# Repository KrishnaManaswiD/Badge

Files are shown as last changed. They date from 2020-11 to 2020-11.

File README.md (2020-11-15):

# Badge
A congratulatory gift for my firends who completed their PhDs with me.   
Front: an engraved name badge with a built in micro-controller and a ruler to measure their tiny egos with.  
Back: a pictorial representation of our theses and a battery holder with a magnetic piece.  

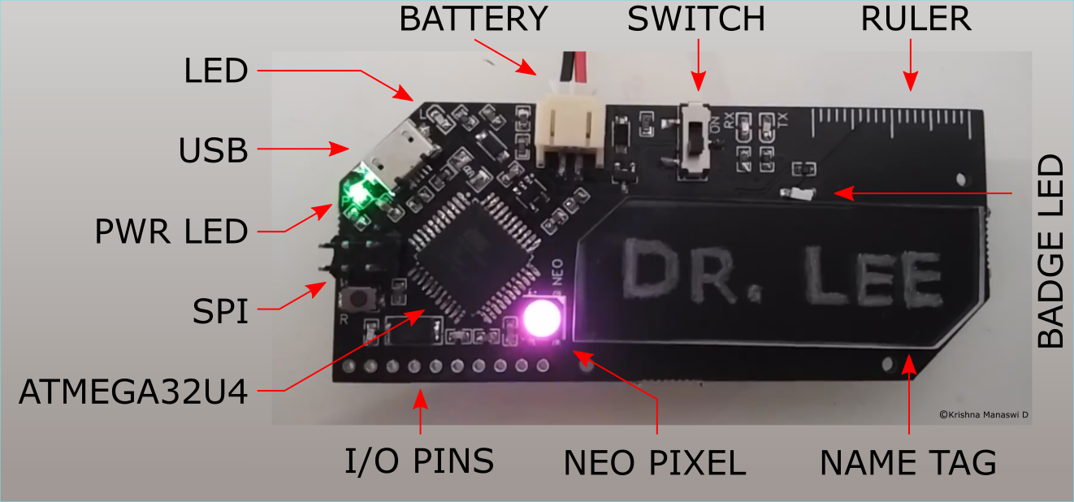
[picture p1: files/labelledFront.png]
The front


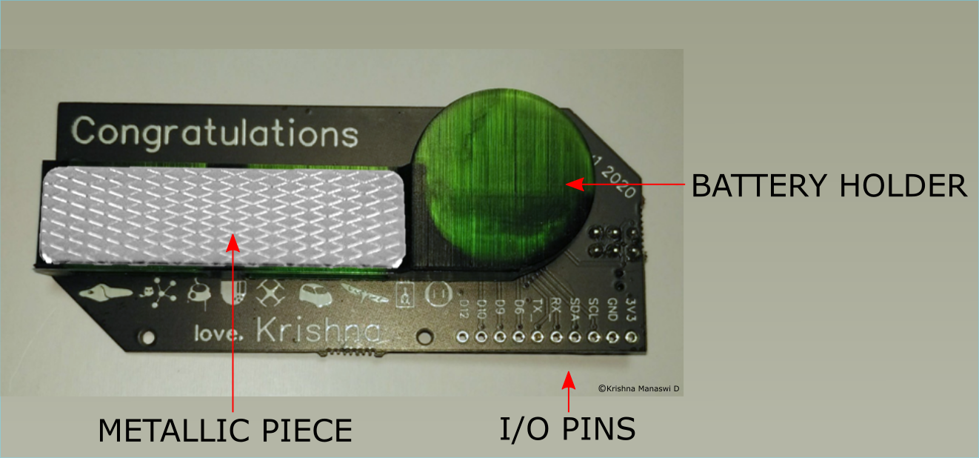
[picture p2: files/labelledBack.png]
The back


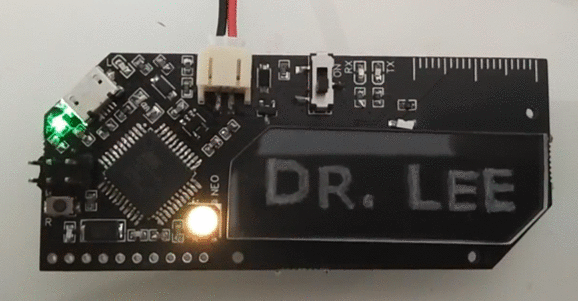
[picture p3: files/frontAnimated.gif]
The badge


- Instructions on building and programming the badge are [here](https://github.com/KrishnaManaswiD/Badge/blob/main/files/Instructions.md).  

- The gerber files can be downloaded from [here](https://github.com/KrishnaManaswiD/Badge/blob/main/files/Gerber_PCB_2020-01-05%2022_20_36.zip).  

- An interactive BOM is located [here](https://htmlpreview.github.io/?https://github.com/KrishnaManaswiD/Badge/blob/main/files/ibom.html). You can also download a csv version from [here](https://github.com/KrishnaManaswiD/Badge/blob/main/files/BOM.csv). 

- A schematic of the circuit is [here](https://github.com/KrishnaManaswiD/Badge/blob/main/files/Schematic_2020-08-21.pdf).  

I used [JLCPCB](https://jlcpcb.com/) to get the boards manufactured. This was the first time that I tried panelising the boards and I am pleased with the resutls.
The black silk screen looks nice. Pictures on the board were printed in sufficient detail. The board was designed using [EasyEDA](https://easyeda.com/). I sourced all the components except the magnetic badge pieces from [LCSC](https://lcsc.com/).

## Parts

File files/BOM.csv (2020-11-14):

Quantity | Name | Designator | Footprint | Manufacturer Part | Manufacturer | Supplier | Supplier Part
2 | 180pF | C1,C2 | 603 | 0603B181K500NT | FH | LCSC | C1598
6 | 10uF | C3,C4,C5,C6,C7,C8 | 603 | CL10A106MP8NNNC | SAMSUNG | LCSC | C85713
1 | 100nF | C9 | C0603 | CL10B104JB8NNNC | SAMSUNG | LCSC | C24452
1 | 1uF | C10 | C0603 | 0603F105M160NT | FH | LCSC | C1689
2 | SCHOTTKY | D1,D2 | SOD-123_L2.8-W1.8-LS3.7-RD | SS0520-R1-00001 | PANJIT International | LCSC | C398783
1 | nSMD025-30V | F1 | 1206 | nSMD025-30V | TECHFUSE | LCSC | C70070
1 | JST_2MM_MALE | J1 | JST-2-SMD | S2B-PH-SM4-TB(LF)(SN) | JST | LCSC | C295747
1 | RED | LED4 | LED0603-R-RD | 19-217/R6C-AL1M2VY/3T | EVERLIGHT | LCSC | C72044
1 | WS2812B | NEO | LED-SMD_4P-L5.0-W5.0-BL | WS2812B | Worldsemi | LCSC | C114585
1 | GREEN | PWR | LED0603-R-RD | 19-217/GHC-YR1S2/3T | EVERLIGHT | LCSC | C72043
1 | DMG3415U-7 | Q1 | SOT-23-3_L2.9-W1.6-P1.90-LS2.8-BR-CW | DMG3415U-7 | Diodes Incorporated | LCSC | C96616
2 | 22 | R1,R2 | 603 | RS-03K220JT | FH | LCSC | C96423
2 | 10K | R3,R8 | 603 | 0603WAF1002T5E | UniOhm | LCSC | C25804
1 | 150K | R4 | 603 | 0603WAF1503T5E | UniOhm | LCSC | C22807
4 | 1K | R5,R6,R7,R9 | 603 | 0603WAJ0102T5E | UniOhm | LCSC | C25585
1 | 100 | R10 | R0603 | 0603WAJ0101T5E | UniOhm | LCSC | C25201
1 | TSA343G00D-250J2 | SW1 | SW-SMD_L4.0-W2.9-P4.15-EH | TSA343G00D-250J2 | BRIGHT | LCSC | C354947
1 | SS-3235D-03-L2 | SW2 | SW-SMD_SS-3235D-03-L2.00 | SS-3235D-03-L2 | XKB Enterprise | LCSC | C381097
2 | BLUE | TX,RX | LED0603-R-RD | 19-217/BHC-ZL1M2RY/3T | EVERLIGHT | LCSC | C72041
1 | ATMEGA32U4-AU | U1 | QFP-44_L10.0-W10.0-P0.80-LS13.2-BL | ATMEGA32U4-AU | MICROCHIP | LCSC | C44854
1 | LP2981-33DBVR | U2 | SOT-23-5_L3.0-W1.7-P0.95-LS2.8-BL | LP2981-33DBVR | TI | LCSC | C129997
1 | SPI Header 6Pin | U3 | SPI HEADER
1 | micro 5P_C77238 | USB1 | MICRO-USB_MICRO-USB-17 | - | LCSC | LCSC | C77238
1 | 8MHZ | X1 | OSC-SMD_L5.0-W3.2 | G5308000201080 | JGHC | LCSC | C390781
10 | hole | 3V3_TAP,GND_TAP,TX_TAP,RX_TAP,SDA_TAP,SCL_TAP,D6/A7/PWM,D9/A9/PWM,D10/A10/PWM,D12/A11 | HOLE | GK001
1 | JST_2MM_Female |  |  | PHR-2 | JST | LCSC | C157955
2 | JST_FEMALE_Crimp |  |  | SPH-002T-P0.5S | JST | LCSC | C111515
1 | LED for Display |  |  | 99-213UMC/2437860/TR8 | Everlight Elec | LCSC | C329181
1 | Magnet Piece |  |  |  |  | Amazon

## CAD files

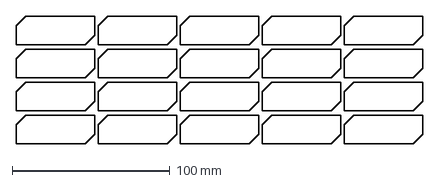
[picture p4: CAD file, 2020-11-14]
files/nameTag.dxf
258.0 x 81.0 mm

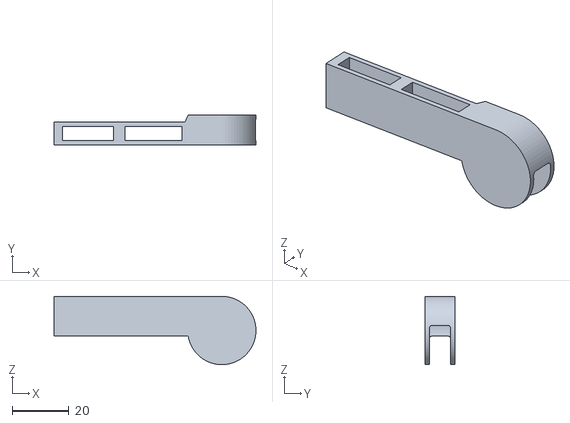
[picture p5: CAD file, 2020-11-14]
files/batteryHolder.stl
71.0 x 10.5 x 24.0

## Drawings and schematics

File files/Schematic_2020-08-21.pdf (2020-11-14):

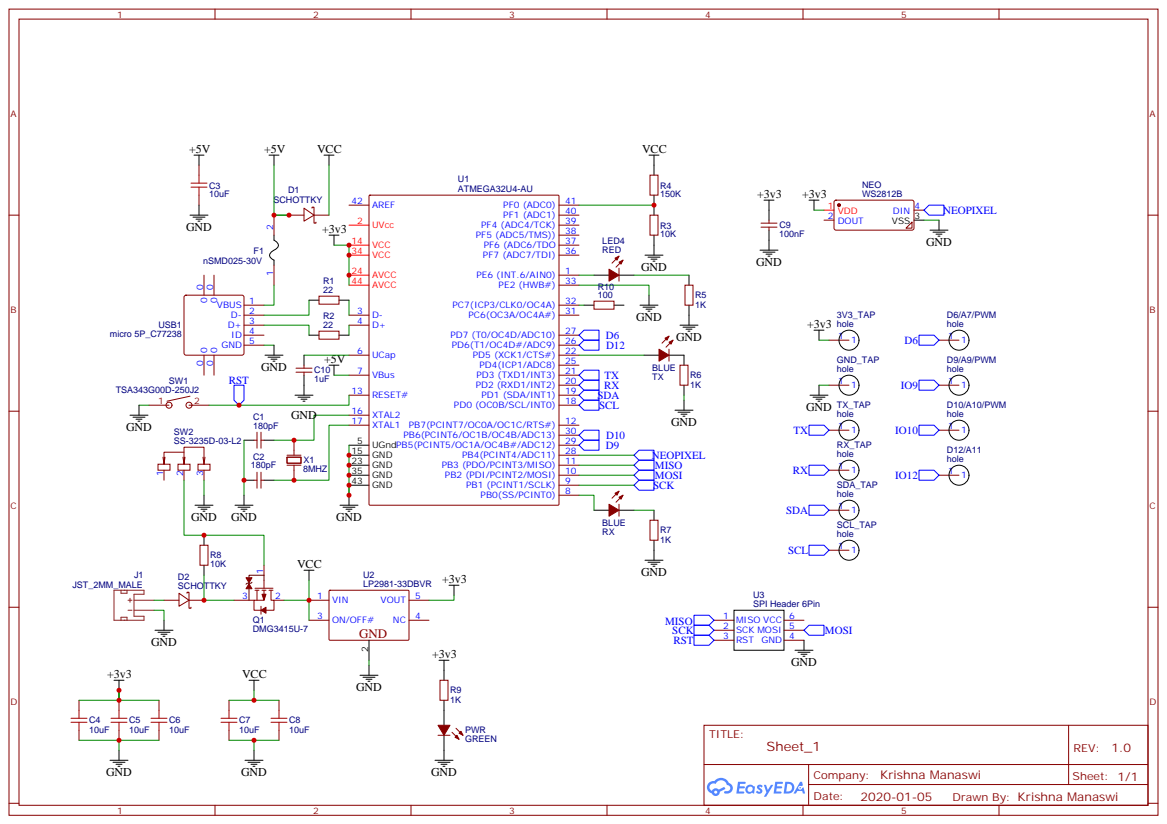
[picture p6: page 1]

PB7(PCINT7/OC0A/OC1C/RTS#) 12
PB2 (PDI/PCINT2/MOSI) 10 PB3 (PDO/PCINT3/MISO) 11 PB4(PCINT4/ADC11) 28 PB5(PCINT5/OC1A/OC4B#/ADC12) 29 PB6(PCINT6/OC1B/OC4B/ADC13) 30

Drawn By: Krishna Manaswi

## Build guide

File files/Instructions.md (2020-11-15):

# Instructions

## Assembly
1. Solder all the components.
2. The name tag is laser-cut out of acrylic. Download the file [here](https://github.com/KrishnaManaswiD/Badge/blob/main/files/nameTag.dxf). I engraved the name by hand, using a rotary tool with a ball attachment. I then glued it to the front of the badge.
3. The battery holder is 3D printed and affixed to the back of the badge. The STL file is located [here](https://github.com/KrishnaManaswiD/Badge/blob/main/files/batteryHolder.stl). I printed it on an Anycubic Photon S.  
4. The metallic piece of the [magnetetic clip](https://www.amazon.com/Magnetic-Name-Badge-Holder/s?k=Magnetic+Name+Badge+Holder) is finally glued to the battery holder.

## Powering the badge
The battery holder is designed to hold two CR2032 batteries (3V each) in the circular portion or a small 3.7V LiPo battery in the rectangular section below the metallic piece.
The badge has an onboard regulator that supplies 3.3V to the chips. Connect the batteries using the JST header. **Be sure to check the polarity.**

The back

## Programming
The board is very similar in design to the [Adafruit Flora](https://www.adafruit.com/product/659). There are a few differences like extra I/O pins and LEDs but you can treat it in a similar manner. To set it up like an Adafruit Flora, you need to burn the correct bootloader. The advantage is that the Arduino IDE recognises the board as a Flora and you can program it through the USB port. The disadvantage is that the additional pin functionality is lost.  

Alternatively, you can treat the board like a programmable chip and write custom code on it through the SPI header.  

Follow the steps below to set it up in whichever way you want. Both methods require the use of a programmer. An Arduino UNO that is set up as an ISP will do fine.

### Convert an Arduino UNO to a programmer
1. Connect a working Arduino UNO to your computer.  
2. Using the Arduino IDE, burn the ArduinoISP sketch from the provided examples.  

Your Arduino UNO is now a programmer. For more details, you can refer [here](https://www.arduino.cc/en/Tutorial/BuiltInExamples/ArduinoISP)

### Connecting the Arduino UNO to the badge
You will need to connect the SPI headers as shown below.
| UNO |  Badge  |
|---|:---:|
| Pin 10  |  RESET  |
| Pin 11  |  MOSI |
| Pin 12  |  MISO |
| Pin 13  |  SCK |
| GND |  GND |
| 3V3 |  3V3 |

If you are looking at the front of the badge, the SPI header is to the left of the ATMEGA32U4 chip. The pins are as follows. The square pad is the GND pin in my design.   
|  RESET  | SCK |  MISO  |
|---|:---:|---:|
| **GND** |**MOSI** |**VCC** |

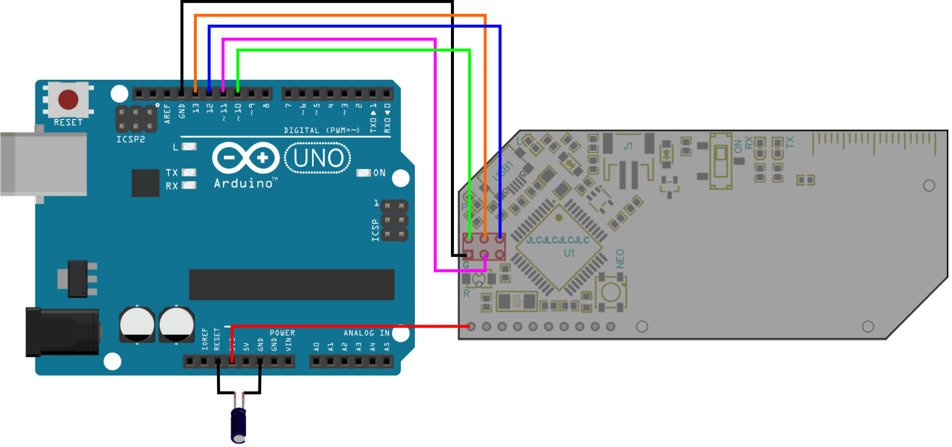
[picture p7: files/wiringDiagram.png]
The front


Note: You will also need to use a 10µF electrolytic capacitor between RESET and GND on the UNO when using it as a programmer. Connect this only after burning the ArduinoISP sketch.  

Additional note: The VCC pin on the badge pcb is not connected to anything else. To power the board during programming, connect the 3V3 pin on the UNO to the 3v3 pin on the badge (first hole on the bottom left). **Be careful that you are using the 3V3 pin from the UNO and not the 5V pin. The badge only runs at 3.3V. You should also be careful that the connection is stable for the entire duration of the programming and does not dislodge as the badge is being programmed.** Else, you risk bricking the board. You can also try providing power with a battery.  

### Option 1: Burning the Adafruit Flora bootloader to the badge
1. First, make sure you have the relevant bootloader. Install the Adafruit boards to the Arduino IDE by following the isntructions [here](https://learn.adafruit.com/adafruit-arduino-ide-setup/arduino-1-dot-6-x-ide).
2. Connect the UNO to the badge as described in the section above. Double check the 3V3 cable.
3. Under Tools -> Board, choose Adafruit Flora.
4. Under Tools -> Port, choose the port that the UNO is connected to.
5. Under Tools -> Programmer, choose Arduinoo as ISP
6. When you are ready, click on Burn Bootloader in the Tools menu.  

Your board should now be detected as an Adafruit Flora. You might have to install the relevant drivers on Windows. See [here](https://learn.adafruit.com/getting-started-with-flora/windows-setup). You dont need the UNO anymore. Use the badge as if you use a regular Arduino. A ton of Flora related tutorials can be found [here](https://learn.adafruit.com/getting-started-with-flora/flora-projects).

### Option 2: No bootloader. Use an UNO to upload a sketch to the badge each time
1. In the Arduino IDE, open the sketch that you want to write to the badge. A demo code is [here](https://github.com/KrishnaManaswiD/Badge/blob/main/files/demo.ino).
2. Coonect the UNO to the badge as described in the section above. Double check the 3V3 cable. 
3. Under Tools -> Port, choose the port that the UNO is connected to.
4. Under Tools -> Programmer, choose Arduinoo as ISP 
5. When ready, go to Sketch -> Upload using programmer. This will write the sketch to the badge.  

If you disconnect the UNO, connect a battery and turn the badge ON, you should see the sketch running.  
You need to use the UNO, that has been set up as a programmer, each time you want to upload a new sketch.  

## Note to friends who received the badges as a gift
I programmed the board using the second method. It is running the demo code that I linked above.  
The red LED at the top left of the board flashes once as soon as you turn on the badge.  
This is followed by two cycles of the Neopixel running through the colours of the rainbow.  
Finally, the LED on the badge glows to highlight the name.  

The badge

## Addressable LEDs and I/O
1. The red LED in the top left of the badge is on pin 7.
2. The LED above the name tag is on pin 13.
3. The neopixel is on pin 8.
4. I/O pins at the bottom are pins 6, 9, 10 and 12.

## Mistakes in the design
1. On the top silkscreen, the ON side of the power switch is indicated incorrectly. The switch is ON when it is towards the bottom end of the badge and OFF when it is towards the top end.
2. The USB connector needs to be grounded. The pcb does not do it. A simple fix is to solder a 0V resistor between the USB casing and a nearby GND pin.
3. The VCC pin on the SPI header is not connected to anything else. This means that during programming, power must be suplied to the board through the 3v3 pin.

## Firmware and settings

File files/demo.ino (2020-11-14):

/* Demo code to run on the badge
 *  Author: Krishna Manaswi Digumarti
 *  Date: Sep 2020
 *  Based on Adafruit's neopixel code
 */

#include <Adafruit_NeoPixel.h>

#define PIN 8
Adafruit_NeoPixel strip = Adafruit_NeoPixel(1, PIN, NEO_GRB + NEO_KHZ800);

int redlED = 7;
int badgeLED = 13;
bool start = false;

void setup()
{
  strip.begin();
  strip.setBrightness(50);
  strip.show(); // Initialize all pixels to 'off'

  pinMode(redlED, OUTPUT); 
  pinMode(badgeLED, OUTPUT);
}

void loop()
{

  if (start == false)
  {
    digitalWrite(redlED, HIGH);   // turn the LED ON
    delay(500);                   // wait for half a second
    digitalWrite(redlED, LOW);    // turn the LED OFF
    delay(500); 
  
    rainbowCycle(20);
    start = true;
  }
  else
  {
    strip.clear();
    strip.show();
    delay(100);
    digitalWrite(badgeLED, HIGH);
  }
}

void rainbowCycle(uint8_t wait)
{
  uint16_t i, j;

  for(j=0; j<256*2; j++) // 2 cycles of all colors on wheel
  { 
    for(i=0; i< strip.numPixels(); i++) 
    {
      strip.setPixelColor(i, Wheel(((i * 256 / strip.numPixels()) + j) & 255));
    }
    strip.show();
    delay(wait);
  }
}

// Input a value 0 to 255 to get a color value.
// The colours are a transition r - g - b - back to r.
uint32_t Wheel(byte WheelPos)
{
  WheelPos = 255 - WheelPos;
  if(WheelPos < 85)
  {
   return strip.Color(255 - WheelPos * 3, 0, WheelPos * 3);
  }
  else if(WheelPos < 170)
  {
    WheelPos -= 85;
   return strip.Color(0, WheelPos * 3, 255 - WheelPos * 3);
  }
  else 
  {
   WheelPos -= 170;
   return strip.Color(WheelPos * 3, 255 - WheelPos * 3, 0);
  }
}

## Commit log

2020-11-13 added interactive bom
2020-11-14 added csv bom and some images
    [BOM.csv]
2020-11-14 added a powerpoint slide to make gif images
2020-11-14 Added gerbers and schematic
2020-11-14 added links to jlcpcb, bom and schematic
2020-11-14 edited bom
2020-11-14 removed pcb.json
2020-11-14 add battery holder stl. simplified file structure
    [BOM.csv, batteryHolder.stl]
2020-11-14 added assembly instructions
2020-11-14 added name tag dxf file
    [nameTag.dxf]
2020-11-15 added wiring diagram
2020-11-15 added wiring diagram to instructions
